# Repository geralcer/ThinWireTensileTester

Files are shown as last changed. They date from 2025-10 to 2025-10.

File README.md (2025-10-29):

Compact Tensile Tester for Carbon Nanotube Wires

This repository contains the mechanical design, Arduino firmware, and MATLAB analysis scripts developed for a compact tensile tester used to characterise fragile filamentary materials such as carbon nanotube (CNT) wires. The device combines a stepper-motor actuator, miniature load cell, and linear potentiometer under Arduino control, achieving sub-micron displacement precision and milli-Newton force resolution.

Repository contents

    /Design/ – STEP files for the mechanical frame, grips, and mounting components.
    /Arduino/ – FINAL_NEW.ino firmware for actuator control, force and displacement acquisition, and serial data output.
    /MATLAB/ –
        loadPlot.m – Loads Arduino output and plots the load–displacement curve with smoothing and zero correction.
        tensilePlotEng.m – Converts load–displacement data to engineering stress–strain, applies compliance correction, and calculates Young’s modulus (YM), ultimate tensile strength (UTS), and strain at break.

Getting started

    Assemble the tester using the provided STEP files.
    Upload FINAL_NEW.ino to your Arduino (tested with Arduino Uno).
    Run a tensile test and save the serial output as a .txt or .csv file.
    Process the data in MATLAB:
        DATA = readtable('test_sample.csv');
        loadPlot(DATA);
        [YM, UTS, Break] = tensilePlotEng(DATA);
        
During execution, tensilePlotEng.m will prompt for lower and upper stress bounds to fit the elastic region and calculate Young’s modulus.

Requirements

    Hardware: Arduino Uno (or equivalent), 2 kg S-beam load cell with amplifier, linear potentiometer, Nema 11 stepper motor.
    Software: Arduino IDE, MATLAB R2021a or later.

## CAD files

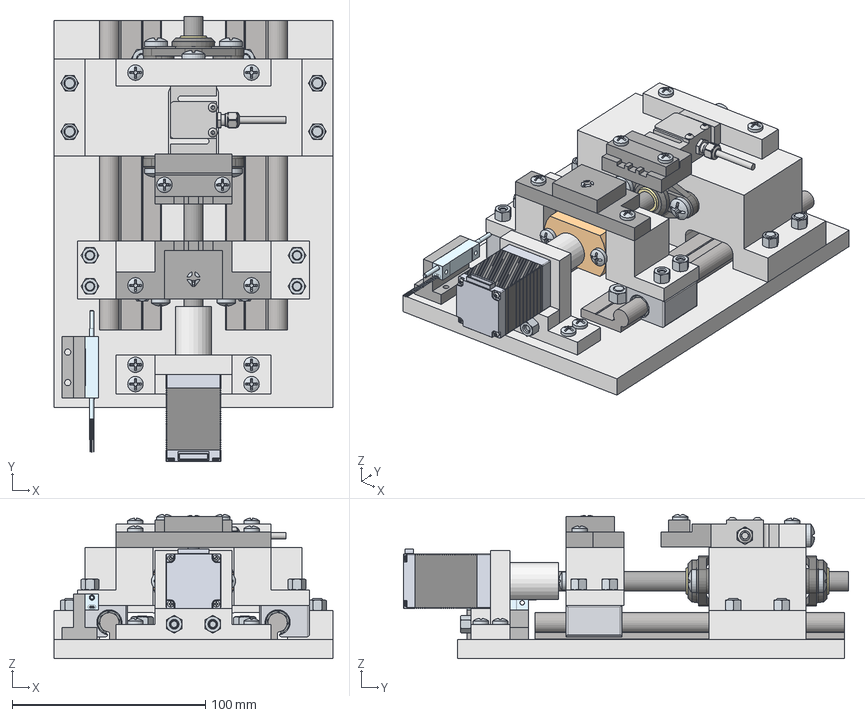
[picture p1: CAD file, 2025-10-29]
Full Body - Tensile tester.step
144.0 x 230.0 x 74.6 mm
PH Pan head screw M2.5x0.45 x 16 x 8
Nema-11 x 12
Stationary Fixture
PH Pan head screw M6x1.00 x 16 x 9
PH Pan head screw M4x0.70 x 12 x 10
Hex nut grade C M5x0.8 x 10
PH Pan head screw M5x0.80 x 25 x 8
Hex nut grade C M6x1 x 4
PH Pan head screw M6x1.00 x 25 x 8
Moving Platform
PH Pan head screw M6x1.00 x 20 x 6
Displacement Mount
Base Plate
PH Pan head screw M5x0.80 x 20 x 2
PH Pan head screw M4x0.70 x 20 x 8
Coupler
nema horizontal
Stationary platform
Nema Vertical
Load cell Mounting
Stationary Platfrom Fix
3048L
Moving fixture
Moving Platform Fix
Lead screw nut
Load cell new
lead screw

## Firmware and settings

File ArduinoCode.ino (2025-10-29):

#include <Arduino.h>
#include <Stepper.h>
#include <HX711_ADC.h>
#include <EEPROM.h>

// Motor steps per revolution. Most steppers are 200 steps or 1.8 degrees/step
#define MOTOR_STEPS 200
#define RPM 30
#define MICROSTEPS 1
#define DIR 8
#define STEP 7
float calVal = 287784;


// 2-wire basic config, microstepping is hardwired on the driver
Stepper stepperRun(MOTOR_STEPS, DIR, STEP);


// Initialize the HX711 library
const int  DOUT = 11;
const int CLK = 12;
HX711_ADC loadCell(DOUT, CLK);


// Variable to store the measured load cell value
//int loadCellValue = 0;

// Pins for the buttons
const int buttonPin1 = 10;  // Change this to the pin connected to the first button
const int buttonPin2 = 9;  // Change this to the pin connected to the second button
const int buttonPin3 = 6;  // Change this to the pin connected to the second button
int counter = 1; // define a counter to keep track of the motors steps


void setup() {
    // Initialize serial communication
  Serial.begin(9600);

   // Set the speed of the stepper motor (in RPM)
  stepperRun.setSpeed(RPM);
  analogReadResolution(14);

  // Initialize the HX711 library
  loadCell.begin();
  loadCell.setCalFactor(calVal);
    loadCell.start(2000, 1);

  // Set button pins as inputs
  pinMode(DIR, OUTPUT);
  pinMode(STEP, OUTPUT);
  pinMode(buttonPin1, INPUT);
  pinMode(buttonPin2, INPUT);
  pinMode(buttonPin3, INPUT);
  analogReadResolution(14);
}


void loop() {
  if (Serial.available() > 0) {
    String input = Serial.readStringUntil('\n');

    if (input == "test1") {
      test1Program();
    } else if (input == "test2") {
      test2Program();
    } else if (input == "test3") {
      test3Program();
    } else {
      Serial.println("Invalid input. Please enter 'test1', 'test2', or 'test3'.");
    }
  }
}

void test1Program() {
  Serial.println("Running test1 program, Manual movement");
  
  while (true) {
    // Read button states
    int buttonState1 = digitalRead(buttonPin1);
    int buttonState2 = digitalRead(buttonPin2);
    int buttonState3 = digitalRead(buttonPin3);

loadCell.update();
float loadCellValue = loadCell.getData();
// Measure analog displacement value
int displacement = analogRead(A0);
float motor_actuation = (counter * 0.01 / 27);         // Gives the motor position according to the stepps sent to the motor. 27 is the gear ratio
float real_displacement = displacement * 12.8 / 16384;  // Converts the digital signal back too mm units (change 1024 to 4096 if 12 bit is used)


    
    // Check button states and move the motor accordingly
    if (buttonState1 == HIGH ) {
            digitalWrite(DIR,HIGH);
digitalWrite(STEP, HIGH);
delayMicroseconds(200);
digitalWrite(STEP, LOW);
delayMicroseconds(200);
digitalWrite(STEP, HIGH);
delayMicroseconds(200);
digitalWrite(STEP, LOW);
delayMicroseconds(200);
Serial.print(loadCellValue,4);
Serial.print(",");
Serial.println(real_displacement,4);

    } else if (buttonState2 == HIGH) {
      //stepper.rotate(-360);  // Move counter-clockwise
      digitalWrite(DIR,LOW);
digitalWrite(STEP, HIGH);
delayMicroseconds(200);
digitalWrite(STEP, LOW);
delayMicroseconds(200);
digitalWrite(STEP, HIGH);
delayMicroseconds(200);
digitalWrite(STEP, LOW);
delayMicroseconds(200);
Serial.print(loadCellValue,4);
Serial.print(",");
Serial.println(real_displacement,4);
    } else if (buttonState3 == HIGH) {
      Serial.println("Manual Movement Terminated, Chose Program to run");
      break;
    } else {

    }
    
    // Delay for stability (adjust as necessary)
    //delay(10);
  }
}


void test2Program() {


  // This programs actuates the machine until the load cell is above a threshhold value
  Serial.println("Started Test 2: automatic pre-tensioning of sample");
  Serial.println("Force:, Displacement:");

  // Threshold value for load cell to stop motor
 float loadThreshold = 0.02; // Adjust this value according to your setuptes
  while (true) {
    // Read load cell value
    loadCell.update();
    float loadCellValue = loadCell.getData();
    // Measure analog displacement value
    int displacement = analogRead(A0);
    // Measure emergency termination button
    int buttonState3 = digitalRead(buttonPin3);
    int goback = 1;
    
    for (int i = 0; i < 10; i++){
    // Check if load cell value is below the threshold
     if (buttonState3 == HIGH) {
      int goback = 0;
      return;
     } else if (loadCellValue > loadThreshold) {
      int goback = 0;
      return;
     }else if (displacement >9500000) {
      Serial.println("Platform moved beyond safe limit, Program aborted");
      int goback = 0;
      return;
      } else  {
      digitalWrite(DIR,LOW);
      digitalWrite(STEP, HIGH);
      delayMicroseconds(1400);
      digitalWrite(STEP, LOW);
      delayMicroseconds(1400);
      digitalWrite(STEP, HIGH);
      delayMicroseconds(1400);
      digitalWrite(STEP, LOW);
      delayMicroseconds(1400);
    } 
    }
   
    // Print motor position and load cell value
    Serial.print(loadCellValue);
    Serial.print(",");
    Serial.println((int)displacement);
    if (goback == 0){
      Serial.println("Pretension mesured, program finished");
      return;
    }
  }
}


void test3Program() {
  analogReadResolution(14);
  int counter = 1;
  Serial.println("Force:, Displacement:, Motor Actuation:");
// This program changes the calibration value of the load cell.
// It functions by applying two knowen loads to the load cell.
while(true){
 // Read load cell value
 loadCell.update();
 float loadCellValue = loadCell.getData();
  // Measure analog displacement value
 int displacement = analogRead(A0);
 // Measure emergency termination button
 int buttonState3 = digitalRead(buttonPin3);


if (displacement < 30 ){
return;
} else if (displacement > 150000000) {
return;
} else if (buttonState3 == LOW ){
 digitalWrite(DIR,LOW);
digitalWrite(STEP, HIGH);
delayMicroseconds(500);
digitalWrite(STEP, LOW);
delayMicroseconds(500);
 //counter = counter + 1;
 ++counter;
 float motor_actuation = (counter*0.01/27); // Gives the motor position according to the stepps sent to the motor. 27 is the gear ratio 
 float real_displacement = displacement*12.8/16383; // Converts the digital signal back too mm units (change 1024 to 4096 if 12 bit is used)

Serial.print(loadCellValue,4);
Serial.print(",");
Serial.print(real_displacement,4);
Serial.print(",");
Serial.println(motor_actuation);

} else {
  Serial.println("Test 3 Terminated, Tensile test Complete");
  return;
}
}
}
